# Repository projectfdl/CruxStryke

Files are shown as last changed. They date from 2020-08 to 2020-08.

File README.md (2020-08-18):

(https://www.projectfdl.com)

# CruxStryke

Welcome to the CruxStryke repository. A brushless mod for the Nerf Motostryke featuring PFDL Crux motors.

## This project is licensed under the terms of the Creative Commons Non-Commercial Attribution Share Alike 4.0 license
Print it, tweak it, share it and if you do and give us props. Please don't sell it without Project FDL permission.

<br>

## Printing your CruxStryke cage

Print your cage from PLA, PETG, ABS or your preferred 3D printing material.<br>
0.2mm or similar layer height with 4 or more perimeters and 30%+ infill.<br>
Use support under the three cage mount holes. Support avoidance on the rest of the cage is suggested but optional.<br>
Drill cage mount holes and motor mount holes with 3mm bit. Use original cage screws to mount cage.<br>
File or sand any rough/drooping areas inside the dart guides especially the upper sections.<br>
See FDL-3 flywheel instructions for printing your flywheels.<br>
The 15 & 16mm dimensions on flywheels indicate diameter formed by concavity of flywheel. 15mm is tighter crush and should produce higher FPS.<br>
Attach flywheels to motors with M2.5x5 flathead screws.<br>
Mount motors to cage with M3x8 socket head screws.<br>
Use thread locker on both flywheel and motor screws.<br>

## Shell mods

Remove dart guides/rails from shell above cage with Dremel or other tool. All other shell mods including battery tray clearing are optional and done at your own discression.

## Electronics

You're on your own past the motors and ESC's. I used an FDL-3 power board and soldered wires directly to an Arduino Pro Mini in mine with a slightly altered FDL-3 semi firmware. There are lots of options and methods out there to spin brushless motors. Be creative;)

### Make on!

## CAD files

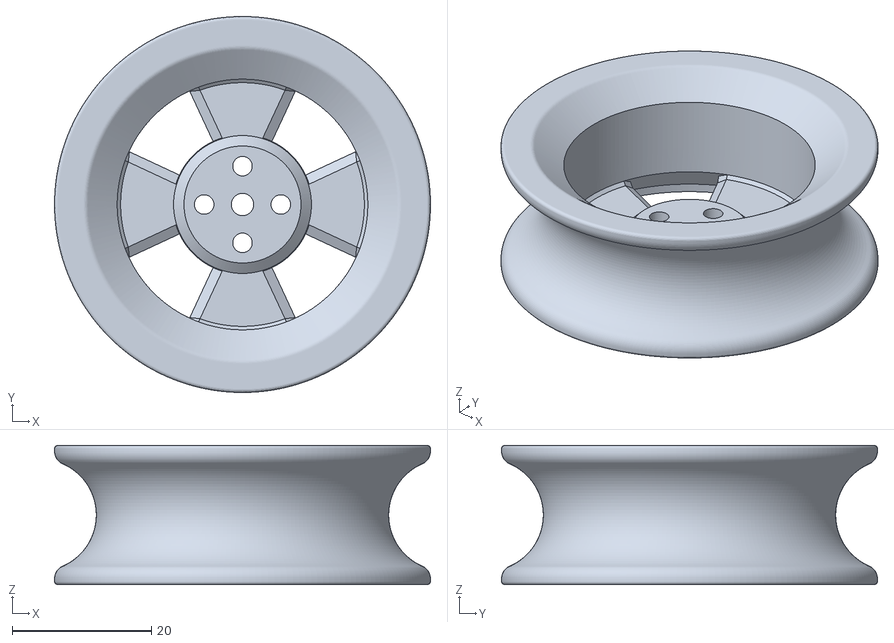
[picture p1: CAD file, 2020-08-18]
CruxStryke Flywheel 16mm.stl
54.0 x 54.0 x 20.0

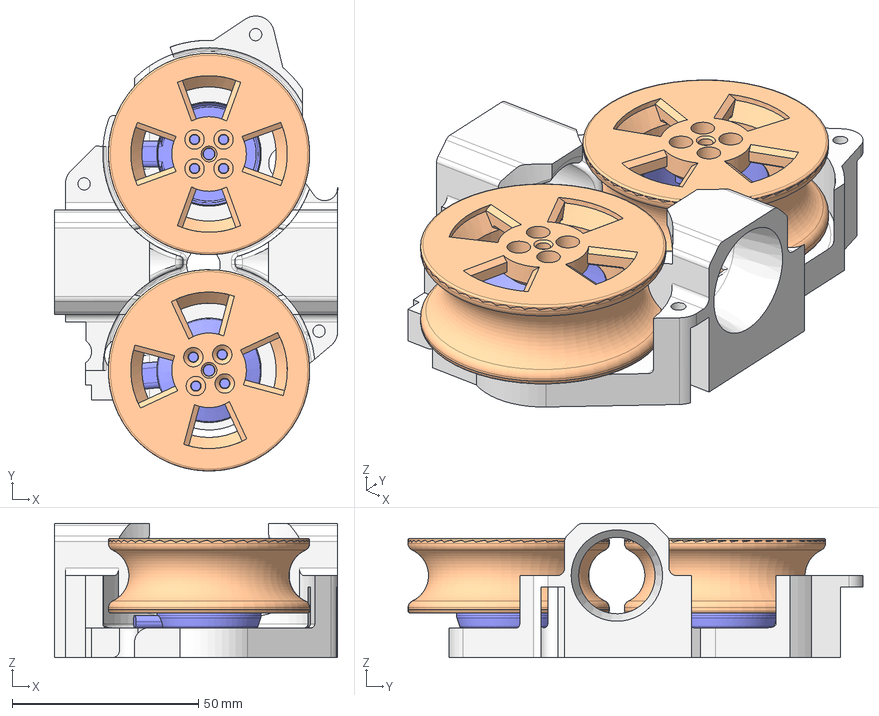
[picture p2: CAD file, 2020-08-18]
CruxStryke Cage.step
76.0 x 122.0 x 36.0 mm
Cage
Crux Motors
Flywheels

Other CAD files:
CruxStryke Flywheel 15mm.stl
CruxStryke Cage.stl
